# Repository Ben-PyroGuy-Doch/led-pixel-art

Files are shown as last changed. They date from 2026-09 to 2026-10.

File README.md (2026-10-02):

# LED Pixel Art — Pico W 8x8 Emoji Light

A tiny, button-driven pixel-art light built around a Raspberry Pi Pico W and an 8x8 WS2812B (NeoPixel) LED matrix. Tap the button to flip through emojis; hold it to switch between still and animated pictures. Built as a hands-on STEM project.



## What's in here

| File | What it is |
|---|---|
| [`main.py`](main.py) | The MicroPython code that runs on the Pico W |
| [`GUIDE.md`](GUIDE.md) | Step-by-step build guide: wiring, Thonny setup, running the code, saving it to the Pico, printing the case |
| [`WORKSHOP.md`](WORKSHOP.md) | A ~2 hour STEM lesson plan built around this project — wiring, coordinates, loops, state machines, 3D printing |
| [`diffuser1-Body.stl`](diffuser1-Body.stl) | 3D-printable frame/case for the Pico + LED matrix (~94 x 84 x 63 mm) |
| [`pixel-art-templates.pdf`](pixel-art-templates.pdf) | Printable 8x8 grid + colour-key worksheets for planning new emoji on paper before typing them in |

## Hardware

- Raspberry Pi Pico W
- 8x8 WS2812B / NeoPixel LED matrix (3-wire: 5V, GND, DIN)
- 3 jumper wires
- USB cable
- 3D printer + PLA (for the case)

## Quick start

1. Wire the LED matrix to the Pico (see `GUIDE.md` Step 1).
2. Install [Thonny](https://thonny.org/) and set the interpreter to MicroPython (Raspberry Pi Pico).
3. Open `main.py` in Thonny and run it.
4. Tap the Pico's BOOTSEL button → next emoji. Hold it (~1s) → toggle still/animated.
5. Save `main.py` onto the Pico itself (File > Save as > Raspberry Pi Pico) so it runs standalone off any USB power.

Full details, including how the zig-zag LED wiring maps to an 8x8 grid and how to draw your own emoji, are in [`GUIDE.md`](GUIDE.md).

### This board, specifically

| | |
|---|---|
| Board | Pico W, MicroPython **v1.23.0** (2024-06-02) |
| Serial port | **COM4** |
| Data pin | GP15 (physical pin 20) → matrix `DIN` |
| Matrix | 8x8, serpentine wiring (`SERPENTINE = True`) |
| Button | BOOTSEL (`USE_BOOTSEL = True`), or a button GP14→GND |

Deploy without opening Thonny, using [`mpremote`](https://docs.micropython.org/en/latest/reference/mpremote.html):

```bash
python -m mpremote connect COM4 fs cp main.py :main.py
python -m mpremote connect COM4 exec "import machine; machine.reset()"
```

- **Close Thonny's connection first** (Run → Disconnect, or close Thonny) — it holds the COM port open and `mpremote` fails with "failed to access COM4 (it may be in use by another program)".
- **Always finish with `machine.reset()`** — an `mpremote` session takes over the REPL and leaves `main.py` stopped otherwise; `soft-reset` isn't reliable for this.
- The reset command usually ends with `SerialException: ClearCommError failed` — **that's the success case**, the board just dropped USB mid-command. Confirm it's back with `python -m mpremote devs` (passive check, won't interrupt the running script).
- **Thonny interrupts `main.py` the moment it connects.** If the board "only works unplugged from the PC," that's why, not a code fault.
- Keep `BRIGHTNESS` at 0.1–0.3. All 64 pixels at full white draws roughly 3.8A — far past what USB can supply, and it will brown out the Pico.
- Verify LED colour order with **green or blue test pixels, never red** — red looks correct even when the colour order is swapped.

## Features

- 8 built-in emojis (smile, cool, heart, daisy, star, ghost, cat, alien), each with its own small animation
- Single button controls both emoji selection (tap) and animation mode (hold)
- Adjustable brightness, animation speed, and LED wiring order (`SERPENTINE`) via constants at the top of `main.py`
- Easy to extend — each emoji is just a Python list of 8-character strings, one letter per LED colour

## Customising

Add your own emoji by drawing an 8x8 grid of letters (see `PALETTE` in `main.py` for the colour key, or print `pixel-art-templates.pdf`), then adding it to the `EMOJIS` list. See `GUIDE.md` Step 7 for the full how-to.

## Status

Tested and working on the physical board. The case (`diffuser1-Body.stl`) is a first-pass frame — print settings and fit are in `GUIDE.md`.

## License

Open source, credit required. The code (`main.py`) is under [Apache 2.0](LICENSE). The
guide, workshop plan, templates and case design are under [CC BY 4.0](LICENSE-docs). Use them,
adapt them, teach with them, and keep the [`NOTICE`](NOTICE) file or credit Ben Docherty.



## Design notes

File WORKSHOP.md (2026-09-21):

# LED Pixel Art — STEM Workshop Plan

**For:** one parent + one child (adapt group size as needed)
**Age guide:** upper primary / early secondary, reading independently
**Time:** ~2 hours, split into 5 modules (stop and resume freely between them)
**Output:** a standalone, 3D-printed LED pixel-art light with a button-driven emoji show

This plan wraps the existing build (`main.py`, `GUIDE.md`, `diffuser1-Body.stl`) into a run-able workshop session: what to say, what to check, and which STEM idea each step is secretly teaching.

---

## Materials checklist

- [ ] Raspberry Pi Pico W
- [ ] 8x8 LED screen (WS2812B / NeoPixel type, 3-wire)
- [ ] 3 jumper wires
- [ ] USB cable + computer with Thonny installed
- [ ] `main.py` (provided)
- [ ] `diffuser1-Body.stl` (provided) + access to a 3D printer
- [ ] Pen and paper (for Module 2's planning exercise)

---

## Learning objectives

By the end, the child should be able to:

1. Explain what each of the 3 wires on the LED screen does (power, ground, data).
2. Read and edit a simple 2D list of characters to change what a picture shows.
3. Explain RGB colour mixing well enough to invent a new colour.
4. Explain, in their own words, what a `for` loop is doing and why it saves typing.
5. Describe the difference between a **tap** and a **hold**, and why the code has to measure time to tell them apart.
6. Say what a "still" list vs "animated" list of pictures does in `EMOJIS` and add one of their own.

---

## Module 1 — Wiring & first light (20 min)

**STEM idea:** *circuits* — power, ground, and a signal wire are three different jobs, and mixing them up is how things break.

1. USB unplugged. Point out the three wires on the screen and ask: which do you think carries power, which is the "return path", and which carries the picture data?
2. Wire it up using `GUIDE.md` Step 1 (5V→VBUS, GND→GND, DIN→GP15).
3. Open Thonny, connect, run the single-pixel snippet from `GUIDE.md` Step 3.
4. **Checkpoint:** one dim red light on. If nothing lights up, this is the moment to recheck wiring — not later once there's more code to untangle.

*Talking point:* ask what would happen if DIN and GND were swapped. (Nothing works, and it's usually not damaging — a good moment to normalise "wired it wrong, no big deal, just fix it.")

## Module 2 — Coordinates & the zig-zag (20 min)

**STEM idea:** *coordinate systems and indexing* — a flat strip of 64 LEDs is turned into an 8x8 grid purely by how the numbers map to positions.

1. Run the row test from `GUIDE.md` Step 4. Confirm rows are straight; if scrambled, flip `SERPENTINE`.
2. On paper, draw an 8x8 grid. Ask the child to number the squares 0–63 the way they think the strip is wired (left-to-right every row). Then show them `pixel_number()` in `main.py` and how the zig-zag (`WIDTH - 1 - x` on odd rows) changes that numbering.
3. Have them predict, before running it, what `np[9]` will look like on the physical screen. Run it and check.

*Why this matters:* this is the same idea as screen pixels, spreadsheet cells, and array indexing generally — a real "aha" moment for how software turns numbers into physical positions.

## Module 3 — Drawing with letters & loops (30 min)

**STEM idea:** *encoding/decoding* (a letter standing in for a colour) and *loops* (why `draw()` doesn't need 64 separate lines).

1. Look at `PALETTE` together. Ask: why use letters instead of typing `(255,0,0)` every time? (Readability — this is exactly why programmers invent shorthand.)
2. Pick an existing picture (e.g. `HEART`) and have the child change a few letters, predicting the result before running it.
3. Walk through `draw()`'s nested loop by hand: cover the code, and have them narrate what it does row by row, like reading a recipe.
4. **Activity:** on paper, design an 8x8 picture as a grid of letters (their own initial, a simple face, anything). Type it in as a new list, following the format of `HEART`.
5. Invent one new colour by adding a line to `PALETTE` (RGB mixing: ask what colour `(255,0,255)` should make before running it).

*Checkpoint:* their own picture is on the screen and they can say what at least 3 of the letters mean.

## Module 4 — Buttons, timing & state (30 min)

**STEM idea:** *input debouncing and state machines* — the code has to actively measure elapsed time to tell a quick tap from a deliberate hold, and it remembers "which mode am I in" between loop cycles.

1. Run `main.py` in full. Tap BOOTSEL — next emoji. Hold it — mode flips (still/animated), screen flashes.
2. Open the code together and find `press_started` and `hold_handled`. Ask: how does the Pico know the difference between a tap and a hold, if both start the same way (button goes down)? Let them find the answer: it's a stopwatch (`time.ticks_diff`) against `HOLD_TIME`.
3. Point at `animated = ANIMATED` near the bottom and the `if animated: ... else: ...` in `show()`. This is a **state variable** — one bit of memory that changes what the same button does next. Ask: what's another device that behaves differently depending on a mode it remembers? (TV remote's input-select, a washing machine dial, a game's pause state are all fair answers.)
4. **Activity:** add one new emoji entry to the `EMOJIS` list — reuse a picture they made in Module 3, give it 2-3 animation frames of their own design, and tune its speed number.

*Checkpoint:* their new emoji appears in the button cycle, in both still and animated mode.

## Module 5 — Saving it for good & the case (20 min, plus print time offline)

**STEM idea:** *firmware vs. a live session* — running code from Thonny is temporary; saving it onto the device's own storage is what makes it work standalone. Plus a first pass at CAD/manufacturing: slicer settings, print orientation, and tolerance (parts that need to physically fit together).

1. Follow `GUIDE.md` Step 6: save `main.py` onto the Pico itself (not "This computer"), unplug from Thonny, power it from something else, and watch it run with no laptop attached.
2. Slice and print `diffuser1-Body.stl` (`GUIDE.md` Step 8). While it prints: ask what they think 15-20% infill means, and why a frame doesn't need to be solid plastic to be strong.
3. Once printed, test-fit the Pico and LED screen into the frame before calling it finished.

---

## Extension challenges (send home / next session)

1. Design a whole new emoji from scratch, animated, and add it to the show.
2. Make one emoji's animation loop faster or slower and describe, in the wiring/timing terms from Module 4, why the number does that.
3. Wire a real push-button (Step in `GUIDE.md`: GP14 + GND) instead of BOOTSEL, and explain what changed in the code (`USE_BOOTSEL = False`) versus what stayed the same.
4. Write a short "user manual" for the finished light — what does a tap do, what does a hold do — as if for someone who's never seen it.

## Facilitator notes

- Every "predict, then run" moment above is deliberate — guessing before testing is the core habit this workshop is trying to build, more than any single Pico fact.
- If short on time, Modules 1–3 alone make a complete, satisfying session (a working, editable pixel-art light) — Modules 4–5 add the button logic and the physical case.
- Keep `BRIGHTNESS` low throughout (0.1–0.3) — worth mentioning why (current draw), not just enforcing it.

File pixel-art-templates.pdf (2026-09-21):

# LED Pixel Art Design Sheet

Plan your emoji here before typing it into main.py

off / black

R

red

O

orange

Y

yellow

G

green

B

blue

C

cyan

P

purple

K

pink

W

white

1. Colour in the squares below (or shade them with the matching letter).
2. Each row becomes one line of code, top row first, left to right.
3. A blank square = "." (off). Type the letters into main.py inside
quote marks, one row per line | like the HEART example on the right.
0 | 1 | 2 | 3 | 4 | 5 | 6 | 7

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
### Your design

0 | 1 | 2 | 3 | 4 | 5 | 6 | 7

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
### Example: HEART

"..RR..RR."
"RRRRRRRR"
"RRRRRRRR"
"RRRRRRRR"
".RRRRRR."
"..RRRR.."
"...RR..."
"........"

LED Pixel Art project Pico W + 8x8 NeoPixel matrix

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

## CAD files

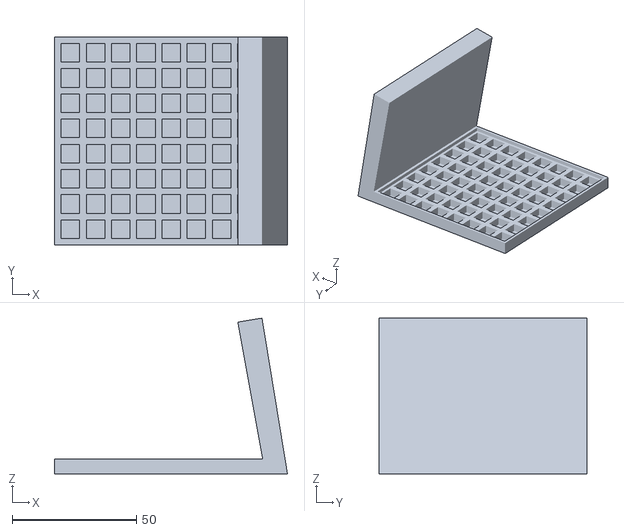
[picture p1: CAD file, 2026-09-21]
diffuser1-Body.stl
93.7 x 83.7 x 62.7

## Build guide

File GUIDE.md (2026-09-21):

# LED Pixel Art Project 🎨💡

Make your own light-up pictures on a screen of 64 tiny coloured lights (an 8x8 grid, like a mini Minecraft screen) — and press a button to flip between them!

**You need:**
- Raspberry Pi Pico W (the little computer)
- 8x8 LED screen (it has 3 wires: power, ground, data)
- 3 jumper wires
- A USB cable
- A computer with **Thonny** installed (free app for writing the code)

---

## Step 1: Wire it up

**Unplug the USB cable first, before touching any wires.**

Connect the 3 wires from the LED screen to the Pico like this:

| Wire on the screen | Goes to this pin on the Pico |
|---|---|
| 5V (or VCC, or +) | **VBUS** — top right corner, next to the USB plug |
| GND (or -) | **GND** |
| DIN (Data In) | **GP15** |

There are two data wires on some screens, DIN and DOUT — make sure you use **DIN**.

## Step 2: Open Thonny and connect the Pico

1. Open Thonny on the computer.
2. Look at the bottom right corner — click there and choose **MicroPython (Raspberry Pi Pico)**.
3. Plug the USB cable in now. You should see `>>>` appear at the bottom of the screen — that means the Pico is talking to the computer.

## Step 3: Make one light turn on

This is just a test, to check the wiring works. Type this into the big box in Thonny, then click the green **Play** button (▶):

```python
from machine import Pin
from neopixel import NeoPixel

np = NeoPixel(Pin(15), 64)
np[0] = (20, 0, 0)
np.write()
```

If one dim red light turns on — great, the wiring's good! If nothing happens, double check DIN is on GP15 and the wires are pushed in properly.

*(Curious what the numbers mean? `(20, 0, 0)` is how much Red, Green and Blue to mix — like mixing paint. `np[0]` means "the first light".)*

## Step 4: Run the real project

1. Open the file `main.py` in Thonny (**File → Open**, then find it on the computer).
2. Click **Play** ▶. A smiley face should appear and start blinking its eyes!
3. Find the little white button on the Pico called **BOOTSEL**.

Here's what the button does:

| What you do | What happens |
|---|---|
| **Quick tap** (press and let go fast) | Shows the **next** emoji |
| **Hold it down** for about 1 second | The screen flashes green or blue, and switches between **wiggling** (animated) and **frozen** (still) pictures |

There are 8 emoji to find: smile, sunglasses, heart, daisy, star, ghost, cat, and alien. Keep tapping to see them all, then try holding the button to see them move!

## Step 5: How the animation actually works

Open `main.py` and look near the bottom for a list called `EMOJIS`. Each emoji has its own line, like this:

```python
("heart", HEART, [HEART, HEART_SMALL, HEART, HEART_SMALL], 0.12)
```

That line means: *"This emoji is called heart. Its normal picture is HEART. When animated, flip between these pictures in this order. Wait 0.12 seconds between each one."*

That's the whole trick behind animation — it's not really moving, it's just **swapping between a few slightly different pictures really fast**, like a mini flipbook. Try changing that last number (`0.12`) to `0.5` and see the heartbeat slow right down.

## Step 6: Save it onto the Pico for good

Right now, the code is only running because Thonny is "lending" it to the Pico. Unplug the USB and it forgets everything! To make it work on its own (like a real light you can plug into any charger):

1. With `main.py` still open, go to **File → Save as...**
2. Choose **Raspberry Pi Pico** as the save location (not "This computer").
3. Name it exactly `main.py`.
4. Now unplug it from the computer and plug it into any USB power — a wall charger, a power bank, anything. The light show should start all by itself.

Want to change the code later? Open Thonny, open `main.py` **from the Pico** this time, make your changes, then save it the same way again.

## Step 7: Design your own emoji

Print out `pixel-art-templates.pdf` — it has blank 8x8 grids and the colour key on paper. Best way to invent a new emoji:

1. **Draw it on paper first.** Colour in squares, or write the letter for each colour.
2. **Find `PALETTE` in `main.py`** — this is the key that turns letters into colours (`R` = red, `B` = blue, `.` = off, and so on).
3. **Type your grid into the code**, one row at a time, 8 letters per row, like:
   ```python
   MYPICTURE = [
       "........",
       "..YY....",
       ".YYYY...",
       "..YY....",
       "........",
       "........",
       "........",
       "........",
   ]
   ```
4. **Add it to the `EMOJIS` list** so the button can find it:
   ```python
   ("mypicture", MYPICTURE, [MYPICTURE], 0.3)
   ```
5. Save and run it — your emoji should now show up when you tap the button!

Want it to move? Draw 2 or 3 slightly different versions (like `MYPICTURE_2`) and list them all instead of just `[MYPICTURE]`.

## Step 8: 3D print the case

There's a file called `diffuser1-Body.stl` — a frame to hold the Pico and LED screen. Print it in PLA, and test-fit the screen and Pico in it once it's done, in case anything needs a little trim.

## Good to know

- Keep the lights dim (`BRIGHTNESS` near the top of the code) — very bright lights use a lot of power.
- Nothing lighting up? Check DIN is on GP15 and the wires are firmly pushed in.
- Colours look wrong (red shows as blue, etc.)? Some screens wire their colours in a different order — ask for help checking this.

## Challenge ideas 🌟

1. Make a smiley that blinks both eyes at once, not just one.
2. Design the first letter of your name.
3. Make a rainbow, one colour per row.
4. Invent a character that "walks" across the screen frame by frame.
5. Make your own colour and give it a name in `PALETTE`.

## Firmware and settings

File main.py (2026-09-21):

# ------------------------------------------------------------
#  EMOJI PIXEL ART on an 8x8 LED screen  -  Raspberry Pi Pico W
#
#  TAP the button        -> next emoji
#  HOLD the button (1s)  -> switch between STILL and ANIMATED
#                           (green flash = animated, blue flash = still)
#
#  Language: MicroPython (use the Thonny app to run it)
# ------------------------------------------------------------
from machine import Pin
from neopixel import NeoPixel
import rp2
import time

# ---------- SETTINGS (safe to change!) ----------
DATA_PIN = 15         # the Pico pin the screen's "DIN" wire is plugged into (GP15)
BRIGHTNESS = 0.1      # 0.0 = off, 1.0 = super bright. Keep it LOW (0.1 - 0.3)!
SERPENTINE = True     # True if your screen's rows zig-zag. If the picture looks scrambled, try False

USE_BOOTSEL = True    # True = use the little white BOOTSEL button on the Pico (great for testing)
BUTTON_PIN = 14       # only used if USE_BOOTSEL is False: button between GP14 and GND

ANIMATED = True       # True = emojis wiggle straight away. False = start with still pictures.
HOLD_TIME = 0.6       # how long to hold the button (in seconds) to swap still <-> animated

WIDTH = 8
HEIGHT = 8

# ---------- COLOUR PALETTE ----------
# Each letter is a colour. Colours are (Red, Green, Blue), each 0 to 255.
PALETTE = {
    ".": (0, 0, 0),         # off (black)
    "R": (255, 0, 0),       # red
    "O": (255, 80, 0),      # orange
    "Y": (255, 200, 0),     # yellow
    "G": (0, 255, 0),       # green
    "B": (0, 0, 255),       # blue
    "C": (0, 200, 200),     # cyan
    "P": (150, 0, 200),     # purple
    "K": (255, 20, 100),    # pink
    "W": (255, 255, 255),   # white
}

# ---------- THE EMOJIS ----------
# 8 rows, 8 letters per row. "." means the light is off.
# Each emoji has a MAIN picture, plus some extra pictures that make it move.


# ===== SMILE =====  (it blinks)
SMILE = [
    "..YYYY..",
    ".YYYYYY.",
    "YYBYYBYY",     # blue eyes, so a blink really shows
    "YYYYYYYY",
    "Y.YYYY.Y",
    "YY....YY",
    ".YYYYYY.",
    "..YYYY..",
]
SMILE_BLINK = [          # both eyes shut (the blue vanishes)
    "..YYYY..",
    ".YYYYYY.",
    "YYYYYYYY",
    "YYYYYYYY",
    "Y.YYYY.Y",
    "YY....YY",
    ".YYYYYY.",
    "..YYYY..",
]
SMILE_WINK = [           # one eye shut, the other still blue
    "..YYYY..",
    ".YYYYYY.",
    "YYBYYYYY",
    "YYYYYYYY",
    "Y.YYYY.Y",
    "YY....YY",
    ".YYYYYY.",
    "..YYYY..",
]


# ===== COOL =====  (a shine slides across the sunglasses)
COOL = [
    "..YYYY..",
    ".YYYYYY.",
    "BBBBBBBB",
    "YBBYYBBY",
    "YYYYYYYY",
    "YY....YY",
    ".YYYYYY.",
    "..YYYY..",
]
COOL_SHINE1 = [
    "..YYYY..",
    ".YYYYYY.",
    "BWBBBBBB",
    "YBBYYBBY",
    "YYYYYYYY",
    "YY....YY",
    ".YYYYYY.",
    "..YYYY..",
]
COOL_SHINE2 = [
    "..YYYY..",
    ".YYYYYY.",
    "BBBBBBBB",
    "YWBYYBBY",
    "YYYYYYYY",
    "YY....YY",
    ".YYYYYY.",
    "..YYYY..",
]
COOL_SHINE3 = [
    "..YYYY..",
    ".YYYYYY.",
    "BBBBBWBB",
    "YBBYYBBY",
    "YYYYYYYY",
    "YY....YY",
    ".YYYYYY.",
    "..YYYY..",
]
COOL_SHINE4 = [
    "..YYYY..",
    ".YYYYYY.",
    "BBBBBBBB",
    "YBBYYWBY",
    "YYYYYYYY",
    "YY....YY",
    ".YYYYYY.",
    "..YYYY..",
]


# ===== HEART =====  (it beats: thump-thump, rest)
HEART = [
    ".RR..RR.",
    "RRRRRRRR",
    "RRRRRRRR",
    "RRRRRRRR",
    ".RRRRRR.",
    "..RRRR..",
    "...RR...",
    "........",
]
HEART_SMALL = [
    "........",
    ".RR..RR.",
    ".RRRRRR.",
    ".RRRRRR.",
    "..RRRR..",
    "...RR...",
    "........",
    "........",
]


# ===== STAR =====  (it twinkles and pulses)
STAR = [
    "...YY...",
    "...YY...",
    "YYYYYYYY",
    ".YYYYYY.",
    "..YYYY..",
    ".YYYYYY.",
    ".YY..YY.",
    "YY....YY",
]
STAR_TWINKLE = [         # white sparks on the tips
    "...WW...",
    "...YY...",
    "WYYYYYYW",
    ".YYYYYY.",
    "..YYYY..",
    ".YYYYYY.",
    ".YY..YY.",
    "WY....YW",
]
STAR_SMALL = [           # arms pulled in
    "........",
    "...YY...",
    ".YYYYYY.",
    "..YYYY..",
    "..YYYY..",
    ".YYYYYY.",
    "..Y..Y..",
    "........",
]


# ===== GHOST =====  (eyes look around, fringe wobbles)
GHOST = [
    "..WWWW..",
    ".WWWWWW.",
    "WWBWWBWW",
    "WWBWWBWW",
    "WWWWWWWW",
    "WWWWWWWW",
    "WWWWWWWW",
    "WW.WW.WW",
]
GHOST_LEFT = [
    "..WWWW..",
    ".WWWWWW.",
    "WBWWBWWW",
    "WBWWBWWW",
    "WWWWWWWW",
    "WWWWWWWW",
    "WWWWWWWW",
    "W.WW.WW.",
]
GHOST_RIGHT = [
    "..WWWW..",
    ".WWWWWW.",
    "WWWBWWBW",
    "WWWBWWBW",
    "WWWWWWWW",
    "WWWWWWWW",
    "WWWWWWWW",
    ".WW.WW.W",
]


# ===== CAT =====  (blinks, then meows)
CAT = [
    "OO....OO",
    "OOO..OOO",
    "OOOOOOOO",
    "OGOOOOGO",
    "OOOOOOOO",
    "OOOKKOOO",
    ".OOOOOO.",
    "..OOOO..",
]
CAT_BLINK = [
    "OO....OO",
    "OOO..OOO",
    "OOOOOOOO",
    "OOOOOOOO",
    "OOOOOOOO",
    "OOOKKOOO",
    ".OOOOOO.",
    "..OOOO..",
]
CAT_MEOW = [             # mouth open
    "OO....OO",
    "OOO..OOO",
    "OOOOOOOO",
    "OGOOOOGO",
    "OOOOOOOO",
    "OOKKKKOO",
    ".OOKKOO.",
    "..OOOO..",
]


# ===== DAISY =====  (middle glows, leaf waves)
DAISY = [
    "..W..W..",
    ".WWWWWW.",
    "WWWYYWWW",
    "WWWYYWWW",
    ".WWWWWW.",
    "...GG...",
    ".G.GG...",
    "..GGG...",
]
DAISY_GLOW = [
    "..W..W..",
    ".WWWWWW.",
    "WWWOOWWW",
    "WWWOOWWW",
    ".WWWWWW.",
    "...GG...",
    ".G.GG...",
    "..GGG...",
]
DAISY_LEAF = [
    "..W..W..",
    ".WWWWWW.",
    "WWWYYWWW",
    "WWWYYWWW",
    ".WWWWWW.",
    "...GG...",
    "...GG.G.",
    "..GGG...",
]


# ===== ALIEN =====  (eyes scan side to side while it talks)
ALIEN = [
    "..GGGG..",
    ".GGGGGG.",
    "GGGGGGGG",
    "GPPGGPPG",
    "GGGGGGGG",
    ".GPPPPG.",
    "..GGGG..",
    "...GG...",
]
ALIEN_LEFT = [
    "..GGGG..",
    ".GGGGGG.",
    "GGGGGGGG",
    "PPGGPPGG",
    "GGGGGGGG",
    ".GGPPGG.",
    "..GGGG..",
    "...GG...",
]
ALIEN_RIGHT = [
    "..GGGG..",
    ".GGGGGG.",
    "GGGGGGGG",
    "GGPPGGPP",
    "GGGGGGGG",
    ".GGPPGG.",
    "..GGGG..",
    "...GG...",
]


# ---------- THE LIST OF EMOJIS ----------
# Each line is:  ("name", still picture, [animation frames], seconds per frame)
#
# TIP: putting the same picture in the list twice makes it stay on screen longer.
#      That is how the smile holds its eyes open, then blinks quickly.

EMOJIS = [
    ("smile", SMILE,
     [SMILE, SMILE, SMILE, SMILE, SMILE_BLINK, SMILE, SMILE, SMILE_WINK], 0.25),

    ("cool", COOL,
     [COOL, COOL_SHINE1, COOL_SHINE2, COOL, COOL_SHINE3, COOL_SHINE4, COOL, COOL], 0.12),

    ("heart", HEART,
     [HEART, HEART_SMALL, HEART, HEART_SMALL, HEART_SMALL, HEART_SMALL, HEART_SMALL], 0.12),

    ("daisy", DAISY,
     [DAISY, DAISY_GLOW, DAISY, DAISY_LEAF], 0.4),

    ("star", STAR,
     [STAR, STAR_TWINKLE, STAR, STAR_SMALL], 0.2),

    ("ghost", GHOST,
     [GHOST, GHOST_LEFT, GHOST, GHOST_RIGHT], 0.35),

    ("cat", CAT,
     [CAT, CAT, CAT_BLINK, CAT, CAT_MEOW, CAT_MEOW], 0.3),

    ("alien", ALIEN,
     [ALIEN, ALIEN_LEFT, ALIEN, ALIEN_RIGHT], 0.3),
]


# ---------- THE CODE THAT MAKES IT WORK ----------
np = NeoPixel(Pin(DATA_PIN), WIDTH * HEIGHT)

if not USE_BOOTSEL:
    button = Pin(BUTTON_PIN, Pin.IN, Pin.PULL_UP)   # pressed = connects to GND


def button_pressed():
    """True while the button is being held down."""
    if USE_BOOTSEL:
        return rp2.bootsel_button() == 1
    return button.value() == 0


def dim(colour):
    """Turn a colour down so it isn't too bright."""
    r, g, b = colour
    return (int(r * BRIGHTNESS), int(g * BRIGHTNESS), int(b * BRIGHTNESS))


def pixel_number(x, y):
    """Work out which LED on the strip is at column x, row y."""
    if SERPENTINE and y % 2 == 1:
        return y * WIDTH + (WIDTH - 1 - x)   # odd rows run backwards
    return y * WIDTH + x


def draw(picture):
    """Draw one picture on the screen."""
    for y in range(HEIGHT):
        for x in range(WIDTH):
            letter = picture[y][x]
            np[pixel_number(x, y)] = dim(PALETTE[letter])
    np.write()   # send it to the LEDs


def flash(colour, times=2):
    """Blink the whole screen one colour, to say 'something changed'."""
    for _ in range(times):
        np.fill(dim(colour))
        np.write()
        time.sleep(0.07)
        np.fill((0, 0, 0))
        np.write()
        time.sleep(0.07)


# ---------- MAIN LOOP ----------
current = 0          # which emoji we are on
frame = 0            # which animation frame we are on
animated = ANIMATED  # still pictures, or moving ones?


def show():
    """Put the right picture on the screen for how we are set up now."""
    name, still, frames, speed = EMOJIS[current]
    if animated:
        draw(frames[frame % len(frames)])
    else:
        draw(still)


show()

was_pressed = False
hold_handled = True                    # stops a long press also counting as a tap
press_started = time.ticks_ms()
last_frame = time.ticks_ms()
hold_ms = int(HOLD_TIME * 1000)

while True:
    now = time.ticks_ms()
    pressed = button_pressed()

    # --- button just went DOWN: start the stopwatch ---
    if pressed and not was_pressed:
        press_started = now
        hold_handled = False

    # --- still held down long enough? swap still <-> animated ---
    if pressed and not hold_handled and time.ticks_diff(now, press_started) >= hold_ms:
        animated = not animated
        hold_handled = True            # only once per press
        flash((0, 255, 0) if animated else (0, 0, 255))
        frame = 0
        last_frame = time.ticks_ms()
        show()

    # --- button just came UP after a quick tap? next emoji ---
    if was_pressed and not pressed and not hold_handled:
        current = (current + 1) % len(EMOJIS)
        frame = 0
        last_frame = now
        show()

    was_pressed = pressed

    # --- move the animation along ---
    if animated:
        name, still, frames, speed = EMOJIS[current]
        if len(frames) > 1 and time.ticks_diff(now, last_frame) >= int(speed * 1000):
            frame = (frame + 1) % len(frames)
            last_frame = now
            draw(frames[frame])

    time.sleep(0.02)                   # tiny pause so the Pico isn't racing flat out

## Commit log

2026-09-21 Initial commit: LED pixel art Pico W project
    [diffuser1-Body.stl]
2026-09-21 Remove stale board-backup reference
2026-10-02 License code under Apache 2.0, docs under CC BY 4.0
    Code (main.py) moves to Apache 2.0, the software equivalent of an
    attribution licence. Guide, workshop, templates and STL stay CC BY 4.0
    in LICENSE-docs. NOTICE carries the required credit.
